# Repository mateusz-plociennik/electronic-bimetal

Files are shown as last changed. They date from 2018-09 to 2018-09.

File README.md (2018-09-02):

# electronic-bimetal

## English
### Description
The system was designed to replace the former used bimetal to temporarily stop the train on an isolated track.

### Programming polarization and timings:
1. Make sure that there is no drive on the insulated track.
2. Press the programming button for approx. 5 seconds, i.e. until the programming LED shines with a stronger light. The polarity of the system is memorized at this time.
3. Insert the drive into the insulated track (preferably to drive in automatically). From that moment, the detention time begins to count.
4. Press the programming button so that the train leaves the insulated path. When the programming button is pressed, the parking time is memorized, while at the moment of releasing the button - driving time.
5. End of programming. The system goes into normal mode.

## Polski
### Opis
Układ został zaprojektowany by zastąpić bimetal używany dawnej do tymczasowego zatrzymywania pociągu na izolowanym torze.

### Programowanie polaryzacji i czasów:
1. Upewnij się, że na izolowanym torze nie ma napędu.
2. Wciśnij przycisk programowania przez ok. 5 sekund, tj. tak długo, aż dioda programowania będzie świeciła mocniejszym światłem. W tym momencie zostaje zapamiętana polaryzacja układu.
3. Wprowadź napęd na izolowany tor (najlepiej, żeby wjechał samoczynnie). Od tego momentu zaczyna się naliczanie czasu zatrzymania.
4. Wciśnij przycisk programowania tak długo, by pociąg zjechał z izolowanego toru. W momencie wciśnięcia przycisku programowania następuje zapamiętanie czasu postoju, natomiast w momencie puszczenia przycisku - czasu jazdy.
5. Koniec programowania. Układ przechodzi w tryb normalny.

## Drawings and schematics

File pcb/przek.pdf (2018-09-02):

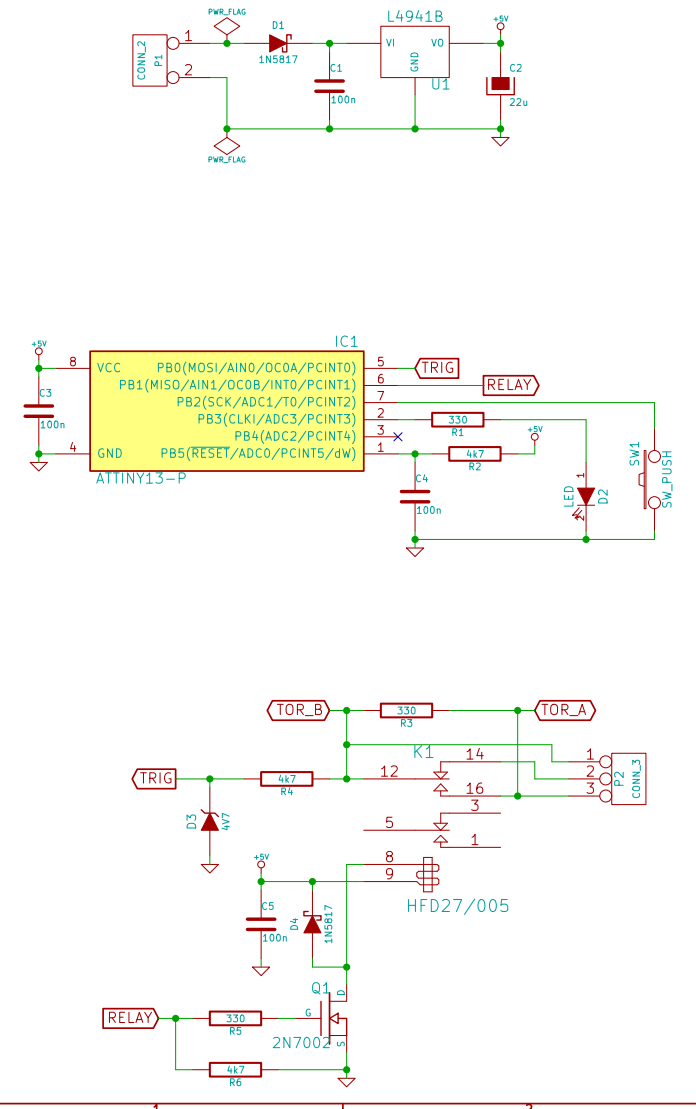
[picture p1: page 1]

Id: 1/1 Title: File: przek.sch
Sheet: /

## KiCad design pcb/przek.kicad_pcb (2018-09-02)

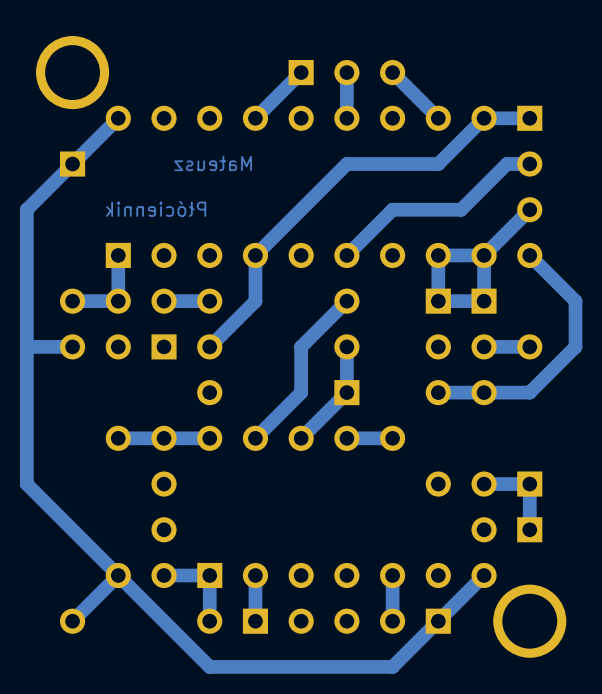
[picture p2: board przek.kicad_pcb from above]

Board: 2 copper layers, 26 parts (0 on the bottom side), 20 nets.

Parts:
C1, C3, C4, C5: 100n; C1
C2: 2u2; C1V5
D1, D4: 1N5817; D3
D2: LED; LED-3MM
D3: 3V3; D3
IC1: ATTINY13-P; DIP-8__300
J1, J2: CONN_3; SIL-3
K1: HFD27/003; DIP-16__300
L1: 10u; R3
M1, M2: P***; 1pin
P1: CONN_4; SIL-4
P2: CONN_3; SIL-3
Q1: BC547B; TO92
R1, R3, R4: 330; R3
R2: 4k7; R3
R5: 4K7; R3
SW1: SW_PUSH; SIL-2
U1: L4931; LM78XX-TO92

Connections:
+5V: C2.1, C5.1, D4.2, K1.16, L1.1, R2.1, U1.VO
GND: C1.2, C2.2, C3.2, C4.2, C5.2, D2.2, D3.1, IC1.4, J2.2, Q1.1, SW1.2, U1.GND
unnamed: D2.1, R1.1
unnamed: IC1.2, SW1.1
unnamed: D1.1, J1.2
unnamed: D4.1, K1.1, Q1.3
unnamed: K1.11, P2.2
unnamed: K1.6, P1.2
unnamed: K1.13, P2.1
unnamed: K1.9, P2.3
unnamed: C1.1, D1.2, U1.VI
unnamed: Q1.2, R5.1
unnamed: IC1.5, R1.2
unnamed: C3.1, IC1.8, L1.2
unnamed: C4.1, IC1.1, R2.2
RELAY: IC1.7, R5.2
TOR_S: K1.4, P1.1, R3.2, R4.1
TOR_Z1: J1.1, J2.1, K1.8, P1.3, R3.1
TOR_Z2: J1.3, J2.3, P1.4
TRIG: D3.2, IC1.6, R4.2

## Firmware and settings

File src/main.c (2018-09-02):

/*
 * main.c
 *
 *  Created on: 2013.07.25
 *      Author: Mateusz Plociennik
 */
#include <stdint.h>

#include <avr/eeprom.h>
#include <avr/io.h>
#include <avr/interrupt.h>
#include <util/delay.h>

/* Pinout of ATtiny13A:
 *            ---\__/---
 *     RESET -|1      8|- VCC
 * (SWI) PB3 -|2      7|- PB2 (RLY)
 * (RES) PB4 -|3      6|- PB1 (TRG)
 *       GND -|4      5|- PB0 (LED)
 *            ----------
 */
#define LED	PB0	// Light-emitting Diode
#define RES	PB4	// Reserved (not connected)
#define RLY	PB2	// Relay Control
#define SWI	PB3	// User Switch
#define TRG	PB1	// Trigger Signal

#define ledOn()				(PORTB |= (1 << LED))
#define ledOff()			(PORTB &= ~(1 << LED))

#define isSwitchReleased()	(PINB & (1 << SWI))

#define relayOn()			(PORTB |= (1 << RLY))
#define relayOff()			(PORTB &= ~(1 << RLY))

#define isTriggerHigh()		(PINB & (1 << TRG))

#define PROG_EN_TIME 	9 // cycles
#define RLY_OPR_TIME 	7 // ms
#define SWITCH_DELAY 	10 // ms

// Cycle time = 435.2 ms
#define LED_ON_TIME		10 // ms
#define LED_OFF_TIME	10 // ms
#define LED_PROG_TIME	20 // ms

enum mode_e
{
	MODE_WAIT 		= 0x01,
	MODE_DELAY 		= 0x02,
	MODE_LATCH		= 0x03,
	MODE_PROG_WAIT 	= 0x11,
	MODE_PROG_DELAY	= 0x12,
	MODE_PROG_LATCH	= 0x13,
};

#define MODE_PROG_MASK	0xF0
#define MODE_ENUM_MASK	0x0F

volatile uint8_t mode = 0;
volatile uint8_t time = 0;

uint8_t EEMEM ee_delay_time = 91;
volatile uint8_t delay_time;
uint8_t EEMEM ee_latch_time = 11;
volatile uint8_t latch_time;
uint8_t EEMEM ee_trigg_pol = 0;
volatile uint8_t trigg_pol;

int main()
{
	// Read EEPROM
	delay_time = eeprom_read_byte(&ee_delay_time);
	latch_time = eeprom_read_byte(&ee_latch_time);
	trigg_pol = eeprom_read_byte(&ee_trigg_pol);

	// Port Pin Configurations
	DDRB = (1 << LED) | (0 << RES) | (1 << RLY) | (0 << SWI) | (0 << TRG);
	PORTB = (0 << LED) | (1 << RES) | (0 << RLY) | (1 << SWI) | (0 << TRG);
	MCUCR = (1 << ISC01) | (trigg_pol ? 1 : 0 << ISC00);

	mode = MODE_WAIT;

	// PWM Phase Correct, clkIO/1024, enable interrupt
	TCCR0A = (0 << WGM01) | (1 << WGM00);
	TCCR0B = (0 << WGM02) | (1 << CS02) | (0 << CS01) | (1 << CS00);

	GIMSK = (1 << INT0); // Enable INT0 interrupt
	TIMSK0 = (1 << TOIE0); // Enable TIM0_OVF interrupt

	sei();

	while (1) {} // infinite loop
}

ISR(INT0_vect)
{
	_delay_ms(SWITCH_DELAY);

	switch (mode)
	{
	case MODE_PROG_WAIT:
		trigg_pol = isTriggerHigh() ? 1 : 0;
		eeprom_update_byte(&ee_trigg_pol, trigg_pol);

		// The falling / rising edge of INT0 generates an interrupt request
		MCUCR = (1 << ISC01) | (trigg_pol ? 1 : 0 << ISC00);

		/* no break */
	case MODE_WAIT:
		++mode;

		TCNT0 = 0;
		time = 0;

		break;
	default:
		break;
	}
}

ISR(TIM0_OVF_vect)
{
	++time;

	switch (mode)
	{
	case MODE_WAIT:
		if (isSwitchReleased())
		{
			time = 0;
		}
		else if (time == PROG_EN_TIME)
		{
			mode = MODE_PROG_WAIT;

			// Any logical change on INT0 generates an interrupt request
			MCUCR = (0 << ISC01) | (1 << ISC00);
		}
		break;
	case MODE_DELAY:
		if (time == delay_time)
		{
			++mode;

			relayOn();
			time = 0;
		}
		break;
	case MODE_LATCH:
		if (time == latch_time)
		{
			mode = MODE_WAIT;

			relayOff();
			time = 0;
		}
		break;
	case MODE_PROG_WAIT:
		break;
	case MODE_PROG_DELAY:
		if (!isSwitchReleased())
		{
			++mode;

			delay_time = time;
			eeprom_update_byte(&ee_delay_time, delay_time);

			relayOn();
			time = 0;
		}
		break;
	case MODE_PROG_LATCH:
		if (isSwitchReleased())
		{
			mode = MODE_WAIT;

			latch_time = time;
			eeprom_update_byte(&ee_latch_time, latch_time);

			relayOff();
			time = 0;
		}
		break;
	default:
		{
			mode = MODE_WAIT;
		}
	}

	uint8_t i;
	for(i = 0; i < (mode & MODE_ENUM_MASK); ++i)
	{
		ledOn();
		if (mode & MODE_PROG_MASK) // Programming mode
		{
			_delay_ms(LED_PROG_TIME);
		}
		else // Normal mode
		{
			_delay_ms(LED_ON_TIME);
		}
		ledOff();
		_delay_ms(LED_OFF_TIME);
	}
}
